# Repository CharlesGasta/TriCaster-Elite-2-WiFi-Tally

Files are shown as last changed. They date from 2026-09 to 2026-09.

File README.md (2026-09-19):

# TriCaster Elite 2 WiFi Tally

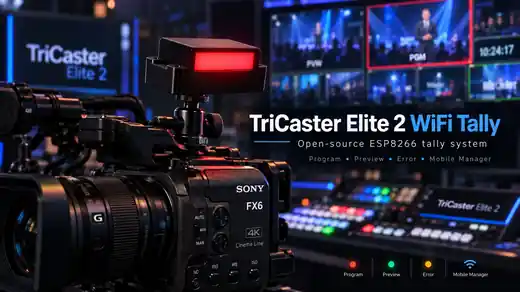
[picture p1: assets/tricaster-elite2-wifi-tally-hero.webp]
TriCaster Elite 2 WiFi Tally


Open-source Wi-Fi tally system for the **NewTek / Vizrt TriCaster Elite 2**, based on inexpensive **ESP8266 NodeMCU** modules.

Each tally unit communicates **directly with the TriCaster Elite 2 over the local network**.  
The optional web Manager is used only for configuration and supervision, so the tally lights continue to work even if the Manager is closed.

---

# Français

## Présentation

Ce projet permet de créer des boîtiers tally Wi-Fi pour **TriCaster Elite 2** à l'aide d'un ESP8266.

Chaque boîtier affiche l'état de la caméra assignée :

- 🔴 **PROGRAM**
- 🟢 **PREVIEW**
- ⚫ **OFF** — ni Program ni Preview
- 🟡 **ERROR** — perte de communication avec le TriCaster
- 🔵 indication réseau / démarrage

Le firmware interroge directement :

```text
http://IP_DU_TRICASTER/v1/dictionary?key=tally
```

Exemple de réponse du TriCaster :

```xml
<column name="input2" index="1" on_pgm="true" on_prev="false" ndi_id="1"/>
```

Le firmware recherche précisément la balise correspondant à `inputX` :

- `on_pgm="true"` → PROGRAM
- `on_prev="true"` → PREVIEW
- les deux à `false` → OFF
- aucune réponse valide pendant environ 2 secondes → ERROR

Le Manager n'est pas indispensable au fonctionnement du tally : les ESP communiquent directement avec le TriCaster Elite 2.

## Matériel nécessaire

Pour chaque tally :

- 1 × **ESP8266 NodeMCU avec USB-C** — modèle utilisé : https://fr.aliexpress.com/item/1005006889833004.html
- 1 × ruban **RGB à anode commune** — modèle utilisé : https://fr.aliexpress.com/item/1005004188897288.html
- **2 LED RGB seulement** sont utilisées dans le boîtier fourni
- 1 × câble **USB-C vers USB-C** pour l'alimentation depuis le port USB-C d'une Sony FX6, ou une alimentation USB-C 5 V classique
- fils, soudure et connecteurs
- 1 × boîtier imprimé en **PLA** à partir du fichier 3D fourni
- 1 × **insert fileté 1/4"** pour fixation sur accessoires caméra — exemple : https://fr.aliexpress.com/item/1005006071559268.html
- accès au même réseau local que le TriCaster Elite 2

Pour l'installation complète :

- 1 × **TriCaster Elite 2**
- 1 × réseau LAN avec Wi-Fi 2,4 GHz
- facultatif : un PC Windows ou le TriCaster lui-même pour exécuter le Manager

> Pour un ruban plus long ou une puissance plus élevée, utilisez des MOSFET/transistors ou un driver LED adapté. Ne faites pas passer une charge importante directement par les sorties de l'ESP8266.

## Réseau Wi-Fi, roaming et installations multi-points d'accès

Le firmware prend en charge **un nombre quelconque de points d'accès Wi-Fi** diffusant le même réseau. Il n'est pas limité à 2 AP : une installation avec **3, 4, 5, 6 AP ou davantage** fonctionne avec la même logique.

### Architecture recommandée

```text
                         ┌── AP 1 ))))
TriCaster ── Switch/LAN ─┼── AP 2 ))))
                         ├── AP 3 ))))
                         ├── AP 4 ))))
                         └── AP N ))))
```

Tous les points d'accès doivent appartenir au **même LAN / même sous-réseau IP** que le TriCaster et les tally.

Pour chaque AP :

- mode **Access Point / Bridge**
- liaison montante **Ethernet filaire** recommandée
- **même SSID**
- **même mot de passe**
- **même mode de sécurité** ; WPA2-PSK est recommandé pour la compatibilité ESP8266
- pas de NAT sur les AP secondaires
- pas de serveur DHCP supplémentaire ; un seul équipement du réseau doit assurer le DHCP
- **Client Isolation / AP Isolation désactivé**
- pas de réseau Guest isolé : les ESP doivent pouvoir joindre le TriCaster et le Manager
- ne pas bloquer l'UDP broadcast local ; le Manager découvre les tally via UDP `4210`
- éviter les fonctions agressives de broadcast/multicast suppression sur le VLAN tally
- les AP peuvent être de marques différentes si ces règles sont respectées
- le 802.11r/k/v n'est pas nécessaire : le firmware ESP8266 gère lui-même la sélection du meilleur BSSID

Évitez le mode répéteur Wi-Fi ou un backhaul radio lorsque vous pouvez tirer un câble Ethernet. Pour une production critique, le **backhaul filaire** est nettement préférable.

### Plan de canaux 2,4 GHz

Utilisez une largeur de canal de **20 MHz** et privilégiez les canaux non chevauchants **1, 6 et 11**.

Exemple pour six AP :

| AP | Canal |
|---|---:|
| AP 1 | 1 |
| AP 2 | 6 |
| AP 3 | 11 |
| AP 4 | 1 |
| AP 5 | 6 |
| AP 6 | 11 |

À partir du 4e AP, réutilisez les canaux en espaçant physiquement autant que possible deux AP utilisant le même canal. Le but est d'éviter que deux cellules voisines émettent sur la même fréquence.

Dans un lieu très grand, une puissance maximale sur tous les AP n'est pas toujours idéale. Commencez avec une puissance adaptée à la zone à couvrir ; si les cellules se chevauchent fortement, réduisez la puissance afin de garder des zones radio distinctes.

Pour une production critique, alimentez idéalement **routeur + switch PoE + AP principaux sur onduleur (UPS)**. Une panne du cœur réseau ferait sinon tomber tous les tally simultanément.

### Roaming automatique des tally

Chaque point d'accès possède un **BSSID** différent, même lorsqu'ils diffusent tous le même SSID. L'ESP8266 garde son IP et choisit automatiquement le BSSID le plus approprié.

Paramètres par défaut :

```cpp
const int ROAM_RSSI_TRIGGER = -70;       // recherche seulement si l'AP courant devient faible
const int ROAM_MIN_GAIN = 8;             // nouvel AP au moins 8 dB meilleur
const unsigned long ROAM_COOLDOWN = 15000;
```

Ainsi, un tally ne change pas d'AP simplement parce qu'un autre est 1 ou 2 dB meilleur. Il reste sur son AP tant que la liaison est correcte, ce qui évite l'effet « yoyo » dans les zones de recouvrement.

Exemple :

```text
AP actuel : -73 dBm
AP voisin : -61 dBm
→ bascule automatique

AP actuel : -71 dBm
AP voisin : -67 dBm
→ aucune bascule
```

Pendant un roaming volontaire, le changement d'AP est **invisible pour le cadreur** : l'ESP conserve le dernier état PROGRAM / PREVIEW / OFF jusqu'à la reprise des données TriCaster.

### Signification des indications réseau

- 🔵 **bleu fixe** : réseau Wi-Fi recherché / hors couverture
- 🔵 **bleu clignotant** : réseau trouvé, association Wi-Fi en cours
- 🟡 **jaune** : Wi-Fi connecté mais communication avec le TriCaster perdue
- lors d'un roaming volontaire vers un meilleur AP : **aucune indication de panne**, le dernier tally reste affiché

Le statut HTTP/heartbeat expose également :

```text
rssi
bssid
channel
wifi_state
```

Ces informations permettent au Manager d'indiquer le point d'accès utilisé par chaque tally et de contrôler la couverture d'une installation multi-AP.

## Boîtier 3D et fixation caméra

Le modèle 3D du boîtier et les informations d'impression sont disponibles sur Thingiverse :

**[Télécharger le modèle 3D sur Thingiverse](https://www.thingiverse.com/thing:7408102)**

Le boîtier est conçu pour être imprimé en **PLA**.

Il prévoit un logement pour un **insert fileté 1/4"**, permettant de fixer directement le tally sur les accessoires de rig caméra courants :

- bras articulé / magic arm
- mini rotule
- adaptateur ou support de griffe flash / cold shoe
- autres accessoires de bijout caméra utilisant une fixation 1/4"

Exemple d'insert utilisé :

https://fr.aliexpress.com/item/1005006071559268.html

Le boîtier a été conçu autour de **2 LED RGB** seulement.

### Alimentation sur caméra

Sur une **Sony FX6**, le tally peut être alimenté directement depuis le port USB-C de la caméra avec un câble **USB-C vers USB-C**.

Si aucun port USB-C caméra n'est disponible, une simple alimentation **5 V USB-C** suffit.

## Câblage

Configuration testée avec ruban RGB **anode commune** :

| ESP8266 | RGB |
|---|---|
| `3V3` | `+` commun |
| `D1` | Vert |
| `D2` | Rouge |
| `D3` | Bleu |

La logique PWM est inversée car il s'agit d'une anode commune.

> Sur beaucoup de cartes NodeMCU, `D3` correspond à GPIO0, qui intervient aussi au démarrage. Si l'ESP refuse de booter avec le ruban connecté, débranchez temporairement cette ligne pendant le flash ou changez le brochage dans le firmware.

## Animation au démarrage

```text
Noir → Rouge → Jaune → Vert → Cyan → Bleu → Magenta → Rouge → Noir
```

puis trois flashs blancs rapides.

## Installation du firmware

1. Installer **Arduino IDE**.
2. Installer **esp8266 by ESP8266 Community**.
3. Sélectionner :
   ```text
   NodeMCU 1.0 (ESP-12E Module)
   ```
4. Ouvrir :
   ```text
   TriCaster_Elite2_Tally_ESP8266.ino
   ```
5. Choisir uniquement le numéro du boîtier avant le premier flash :

```cpp
#define DEFAULT_TALLY_NUMBER 1
```

> **Important :** `DEFAULT_TALLY_NUMBER` sert uniquement lorsqu'aucune configuration valide n'est encore enregistrée dans l'EEPROM. Si un ESP a déjà été configuré comme `TALLY-06 / CAM 6`, le reflasher avec `DEFAULT_TALLY_NUMBER 5` **ne le renomme pas automatiquement** : la configuration EEPROM est volontairement conservée. Le nom et la caméra peuvent être changés depuis le Manager, ou l'EEPROM peut être effacée pour repartir comme un boîtier neuf.

6. Compiler puis téléverser.

Le firmware V4 conserve toujours des valeurs par défaut compilables :

```cpp
const char* DEFAULT_WIFI_SSID = "YOUR_WIFI_SSID";
const char* DEFAULT_WIFI_PASSWORD = "YOUR_WIFI_PASSWORD";
const char* DEFAULT_ADMIN_TOKEN = "CHANGE_ME";
```

Mais **il n'est plus nécessaire de reflasher le tally pour changer le réseau**.

Moniteur série :

```text
115200 baud
```

---

## Configuration réseau sans reflasher

### Premier démarrage / réseau introuvable

Au démarrage, le tally cherche le réseau enregistré. S'il ne le trouve pas pendant environ **30 secondes**, il crée automatiquement son propre point d'accès :

```text
TALLY-01-SETUP
TALLY-02-SETUP
...
```

Le mot de passe de ce Wi-Fi SETUP est le **token administrateur**. Sur un firmware neuf, la valeur initiale est :

```text
CHANGE_ME
```

Connectez un téléphone ou un ordinateur au réseau `TALLY-XX-SETUP`, puis ouvrez :

```text
http://192.168.4.1/
```

Le portail permet de régler :

- nom du tally
- SSID Wi-Fi 2,4 GHz
- mot de passe Wi-Fi
- mode **DHCP** ou **IP statique**
- IP, gateway, subnet et DNS en mode statique
- IP du TriCaster
- token administrateur

Après validation, l'ESP enregistre la configuration en EEPROM puis redémarre.

> Pour la sécurité, remplacez immédiatement `CHANGE_ME` par un token personnel de **8 à 32 caractères**. Ce token protège l'API d'administration, la mise à jour OTA et le réseau de secours `TALLY-XX-SETUP`.

### DHCP ou IP statique

Les deux modes sont supportés.

**IP statique** est pratique pour un parc broadcast fixe :

```text
TALLY-01 : 192.168.1.81
TALLY-02 : 192.168.1.82
...
```

Gardez ces adresses **hors de la plage DHCP** du routeur.

**DHCP** est pratique lorsque le système est déplacé sur des réseaux différents. Pour conserver des adresses prévisibles, utilisez de préférence des **réservations DHCP** sur le routeur.

Le Manager V4 permet ensuite de modifier ces paramètres à distance sans reflasher l'ESP.

### Migration depuis l'ancien firmware

Le firmware V4 reconnaît automatiquement la configuration EEPROM de la version précédente et conserve notamment :

- nom du tally
- IP statique
- IP TriCaster
- caméra assignée
- couleurs PROGRAM / PREVIEW
- luminosité

Les nouveaux paramètres réseau sont ajoutés avec leurs valeurs par défaut.

---

## Affectation caméra / entrée

Par défaut :

```cpp
config.camera = constrain(DEFAULT_TALLY_NUMBER, 1, 8);
```

Donc :

```text
TALLY-01 → input1
TALLY-02 → input2
TALLY-03 → input3
...
```

L'affectation peut ensuite être modifiée depuis le Manager sans reflasher l'ESP.

---

## Tally Manager V4.1

### Téléchargement Windows prêt à l'emploi

La dernière version compilée est publiée dans **GitHub Releases** :

https://github.com/CharlesGasta/TriCaster-Elite-2-WiFi-Tally/releases/latest

Téléchargez `TriCaster_Elite2_Tally_Manager.exe`. Si une tâche planifiée Windows lance déjà une ancienne version par un nom de fichier précis, remplacez simplement l'ancien EXE au même emplacement **en conservant exactement le nom attendu par la tâche**.

Fichier source :

```text
TriCaster_Elite2_Tally_Manager.py
```

Le Manager n'est toujours **pas dans le chemin critique du tally** : si le Manager est fermé, chaque ESP continue à lire directement le TriCaster.

Le Manager V4.1 fournit :

- détection automatique des tally
- état connecté / hors ligne
- RSSI avec indication visuelle de qualité
- **BSSID / point d'accès utilisé**
- nom convivial des AP, par exemple `AP TERRAIN`, `AP TRIBUNE`
- canal Wi-Fi
- état Wi-Fi : `connected`, `roaming`, `searching`, `connecting`
- version firmware
- uptime ESP
- latence de réponse TriCaster
- compteur de roamings
- compteur de pertes Wi-Fi
- compteur de pertes TriCaster
- affectation caméra 1 à 32
- couleurs PROGRAM / PREVIEW
- luminosité
- Identify
- reboot distant
- configuration complète du réseau ESP
- DHCP / IP statique
- modification de l'IP TriCaster
- **PRE-FLIGHT / GO-NO-GO** avant production : tally attendus, online/offline, RSSI, latence TriCaster, doublons IP/caméra, versions firmware et cohérence de l'IP TriCaster
- **MODE PRODUCTION** persistant : verrouille OTA, reboot, Identify, affectations, couleurs, luminosité et configuration réseau
- **OTA sécurisée** par tally, sélection ou parc complet : redémarrage et retour sain vérifiés avant de passer au boîtier suivant, avec arrêt au premier échec
- **journal persistant des incidents et actions** avec export CSV : pertes Wi-Fi/TriCaster, roaming, offline/recovery, reboot, OTA et changements de configuration
- **mise à jour OTA de tous les tally connectés**
- interface desktop et mobile

Ports utilisés :

| Fonction | Port |
|---|---|
| Interface web Manager | TCP `8099` |
| Discovery / heartbeat | UDP `4210` |
| API / OTA ESP8266 | TCP `80` |

Interface locale :

```text
http://127.0.0.1:8099
```

Depuis un téléphone sur le même réseau :

```text
http://IP_DU_PC_MANAGER:8099/mobile
```

### Authentification

Le Manager et les opérations d'administration des ESP utilisent une authentification HTTP Basic :

```text
Utilisateur : admin
Mot de passe : token administrateur
```

La configuration persistante du Manager est enregistrée à côté du script / EXE dans :

```text
tally_manager_config.json
```

Valeur initiale publique :

```json
{
  "api_token": "CHANGE_ME",
  "ap_aliases": {},
  "production_mode": false,
  "expected_tally_count": 0
}
```

Remplacez `CHANGE_ME` par le **même token que celui configuré dans les ESP** avant une utilisation sur un réseau partagé.

> Le protocole d'administration reste HTTP sur le LAN. Le réseau tally doit donc rester privé / isolé et ne doit pas être exposé directement à Internet.

### Mise à jour OTA

1. Dans Arduino IDE, compilez le firmware et exportez le binaire `.bin`.
2. Ouvrez le Manager V4.
3. Sélectionnez le fichier `.bin` dans **Firmware OTA**.
4. Cliquez **METTRE À JOUR TOUS LES TALLY**.

Le Manager envoie le firmware séquentiellement à tous les tally actuellement en ligne. Chaque ESP redémarre automatiquement après une mise à jour réussie.

Conservez toujours un premier boîtier de test avant de lancer une mise à jour de parc pendant une période de production.

### PRE-FLIGHT et mode production

Avant un direct, renseignez le nombre de tally attendus puis cliquez **CHECK PRODUCTION**.

Le Manager retourne :

```text
GO         aucun problème détecté
ATTENTION  avertissement non bloquant
NO-GO      au moins une erreur critique
```

Le contrôle vérifie notamment les boîtiers en ligne, le RSSI, la latence et la fraîcheur des données TriCaster, les doublons IP/caméra, les versions firmware et la cohérence de l'adresse TriCaster.

Après validation, activez **MODE PRODUCTION**. Le verrou est persistant et reste actif après un redémarrage du Manager. Il bloque côté serveur les commandes susceptibles de perturber un direct : OTA, reboot, Identify, affectations, couleurs, luminosité et configuration réseau.

### OTA sécurisée V4.1

L'OTA peut cibler :

- un seul tally
- une sélection de tally
- tous les tally en ligne

Les boîtiers sont traités **séquentiellement**. Après chaque envoi, le Manager attend un vrai redémarrage puis vérifie que le boîtier est revenu avec Wi-Fi connecté et données TriCaster fraîches. Par défaut, le déploiement s'arrête au premier échec.

### Journal persistant

Le Manager crée à côté de l'EXE / du script :

```text
tally_manager_events.csv
```

Le journal conserve les événements importants avec date et heure : offline/recovery, pertes Wi-Fi, pertes TriCaster, roaming, erreurs tally, reboot, changements de configuration et OTA. Il est consultable dans l'interface et exportable en CSV. Une rotation automatique conserve le journal précédent lorsque le fichier courant dépasse environ 5 Mo.

### Diagnostic de couverture

Chaque heartbeat expose notamment :

```text
firmware
rssi
bssid
channel
wifi_state
uptime_ms
tricaster_latency_ms
last_tally_age_ms
roam_count
wifi_loss_count
tricaster_loss_count
last_roam_age_ms
```

Repères pratiques pour le RSSI :

```text
>= -65 dBm     très bon
-66 à -72 dBm  acceptable / à surveiller
< -72 dBm      zone à améliorer
```

---

## Compiler le Manager en EXE

Installer PyInstaller :

```powershell
py -m pip install pyinstaller
```

Version avec console :

```powershell
py -m PyInstaller --noconfirm --clean --onefile --console --name TriCaster_Elite2_Tally_Manager TriCaster_Elite2_Tally_Manager.py
```

Version silencieuse pour fonctionnement en arrière-plan :

```powershell
py -m PyInstaller --noconfirm --clean --onefile --windowed --name TriCaster_Elite2_Tally_Manager TriCaster_Elite2_Tally_Manager.py
```

L'exécutable sera dans :

```text
dist\TriCaster_Elite2_Tally_Manager.exe
```

---

## Démarrage automatique sur le TriCaster

Avec le **Task Scheduler** Windows :

```text
Trigger                 : At log on
Run only when logged on : Yes
Run with highest privileges
Action                  : TriCaster_Elite2_Tally_Manager.exe
If already running      : Do not start a new instance
```

Cela fonctionne particulièrement bien sur un TriCaster configuré avec ouverture automatique de session Windows.

---

# English

## Overview

This project provides low-cost Wi-Fi tally units for the **NewTek / Vizrt TriCaster Elite 2** using ESP8266 NodeMCU boards.

Each tally reads the TriCaster tally state directly over the local network and displays:

- 🔴 **PROGRAM**
- 🟢 **PREVIEW**
- ⚫ **OFF**
- 🟡 **ERROR / TriCaster connection lost**
- 🔵 network/startup indication

The ESP8266 queries:

```text
http://TRICASTER_IP/v1/dictionary?key=tally
```

A typical response contains:

```xml
<column name="input2" index="1" on_pgm="true" on_prev="false" ndi_id="1"/>
```

The firmware isolates the exact `inputX` XML element:

- `on_pgm="true"` → PROGRAM
- `on_prev="true"` → PREVIEW
- both `false` → OFF
- no valid response for roughly 2 seconds → ERROR

The optional Manager is not part of the critical tally path. Each ESP communicates directly with the TriCaster Elite 2.

## Required hardware

For each tally:

- 1 × **ESP8266 NodeMCU with USB-C** — board used: https://fr.aliexpress.com/item/1005006889833004.html
- 1 × **common-anode RGB LED strip** — strip used: https://fr.aliexpress.com/item/1005004188897288.html
- the supplied enclosure uses **2 RGB LEDs only**
- 1 × **USB-C to USB-C cable** for power from a Sony FX6 USB-C port, or a standard 5 V USB-C power supply
- wiring / solder / connectors
- 1 × **PLA** 3D-printed enclosure using the supplied model
- 1 × **1/4-inch threaded insert** for camera-rig mounting — example: https://fr.aliexpress.com/item/1005006071559268.html
- access to the same network as the TriCaster Elite 2

Overall system:

- 1 × **TriCaster Elite 2**
- LAN with 2.4 GHz Wi-Fi
- optional Windows computer, or the TriCaster itself, for the Manager

## Wi-Fi network, roaming and multi-AP deployments

The firmware supports **any number of Wi-Fi access points** broadcasting the same network. It is not limited to two APs: deployments with **3, 4, 5, 6 or more APs** use the same roaming logic.

Recommended topology:

```text
                         ┌── AP 1 ))))
TriCaster ── Switch/LAN ─┼── AP 2 ))))
                         ├── AP 3 ))))
                         ├── AP 4 ))))
                         └── AP N ))))
```

All APs must be on the **same Layer-2 LAN / IP subnet** as the TriCaster and tally units.

Configure every AP with:

- **Access Point / Bridge** mode
- preferably a **wired Ethernet backhaul**
- the **same SSID**
- the **same password**
- the **same security mode**; WPA2-PSK is recommended for ESP8266 compatibility
- no NAT on secondary APs
- no additional DHCP server; use one DHCP server for the LAN
- **Client Isolation / AP Isolation disabled**
- do not use an isolated guest network; ESP units must reach the TriCaster and Manager
- allow local UDP broadcast; the Manager discovers tally units on UDP `4210`
- avoid aggressive broadcast/multicast suppression on the tally VLAN
- different AP brands are acceptable when these requirements are met
- 802.11r/k/v is not required; the ESP8266 firmware performs its own BSSID selection

For production use, wired backhaul is strongly preferred over wireless repeater/mesh backhaul.

### 2.4 GHz channel plan

Use **20 MHz** channel width and the non-overlapping channels **1, 6 and 11**.

For six APs, a typical plan is:

| AP | Channel |
|---|---:|
| AP 1 | 1 |
| AP 2 | 6 |
| AP 3 | 11 |
| AP 4 | 1 |
| AP 5 | 6 |
| AP 6 | 11 |

From the fourth AP onward, reuse channels only with as much physical separation as practical between APs sharing the same channel.

For critical productions, power the **router + PoE switch + main APs from a UPS** whenever practical. A failure of the network core would otherwise affect every tally at once.

### Automatic roaming

Every AP has a different **BSSID**, even when all APs use the same SSID. The tally keeps its IP address and automatically selects a better BSSID when necessary.

Default V4.2 roaming parameters:

```cpp
const int ROAM_RSSI_TRIGGER = -72;
const int ROAM_MIN_GAIN = 10;
const unsigned long ROAM_SCAN_INTERVAL = 30000;
const unsigned long ROAM_COOLDOWN = 30000;
const unsigned long ROAM_STARTUP_GRACE = 30000;
```

Initial connection and recovery use standard **SSID + password** association. A specific BSSID is forced only during an intentional roaming handoff to a clearly stronger AP. No proactive roaming scan is allowed during the first 30 seconds after a Wi-Fi connection.

The tally therefore stays on its current AP while the link remains usable and only moves when another AP is clearly better, preventing ping-pong roaming in overlap areas.

During intentional roaming, the switch is **invisible to the camera operator**: the last PROGRAM / PREVIEW / OFF state remains displayed until TriCaster polling resumes.

Network indications:

- 🔵 **solid blue**: searching for the Wi-Fi network / out of coverage
- 🔵 **blinking blue**: network found, Wi-Fi association in progress
- 🟡 **yellow**: Wi-Fi is connected but TriCaster communication is lost
- intentional roaming: no fault indication; the previous tally state is held

The status/heartbeat payload also includes `rssi`, `bssid`, `channel` and `wifi_state` for multi-AP diagnostics.

## 3D-printed enclosure and camera mounting

The enclosure 3D model and print information are available on Thingiverse:

**[Download the 3D model on Thingiverse](https://www.thingiverse.com/thing:7408102)**

The enclosure is designed to be printed in **PLA**.

It includes a seat for a **1/4-inch threaded insert**, allowing the tally to be mounted to common camera-rig accessories such as:

- magic arms / articulated arms
- mini ball heads
- cold-shoe / flash-shoe adapters
- other camera accessories using a 1/4-inch mounting thread

Example threaded insert:

https://fr.aliexpress.com/item/1005006071559268.html

The enclosure is designed around **2 RGB LEDs only**.

### Camera power

On a **Sony FX6**, the tally can be powered directly from the camera's USB-C port using a **USB-C to USB-C cable**.

If camera USB-C power is not available, any standard **5 V USB-C power supply** is sufficient.

## Wiring

| ESP8266 | RGB |
|---|---|
| `3V3` | Common `+` |
| `D1` | Green |
| `D2` | Red |
| `D3` | Blue |

The firmware uses inverted PWM for a common-anode RGB strip.

## Firmware installation

1. Install Arduino IDE.
2. Install **esp8266 by ESP8266 Community**.
3. Select:
   ```text
   NodeMCU 1.0 (ESP-12E Module)
   ```
4. Open:
   ```text
   TriCaster_Elite2_Tally_ESP8266.ino
   ```
5. Select the tally number before the first flash:

```cpp
#define DEFAULT_TALLY_NUMBER 1
```

> **Important:** `DEFAULT_TALLY_NUMBER` is only used when no valid configuration is already stored in EEPROM. If an ESP is already configured as `TALLY-06 / CAM 6`, reflashing it with `DEFAULT_TALLY_NUMBER 5` **will not rename it automatically**: the saved EEPROM configuration is intentionally preserved. Change the name/camera from the Manager, or erase EEPROM to start as a new unit.

6. Compile and upload.

V4 still contains compile-time fallback defaults:

```cpp
const char* DEFAULT_WIFI_SSID = "YOUR_WIFI_SSID";
const char* DEFAULT_WIFI_PASSWORD = "YOUR_WIFI_PASSWORD";
const char* DEFAULT_ADMIN_TOKEN = "CHANGE_ME";
```

However, **network settings no longer require reflashing the ESP**.

Serial monitor:

```text
115200 baud
```

## Network setup without reflashing

### First boot / configured Wi-Fi unavailable

At startup, the tally searches for the stored Wi-Fi network. If it cannot find it for about **30 seconds**, it automatically creates:

```text
TALLY-01-SETUP
TALLY-02-SETUP
...
```

The SETUP Wi-Fi password is the **administrator token**. On a new public firmware build the initial value is:

```text
CHANGE_ME
```

Connect a phone or computer to `TALLY-XX-SETUP`, then open:

```text
http://192.168.4.1/
```

The setup portal can configure:

- tally name
- 2.4 GHz Wi-Fi SSID
- Wi-Fi password
- **DHCP** or **static IP**
- IP, gateway, subnet and DNS in static mode
- TriCaster IP
- administrator token

The ESP saves the configuration to EEPROM and reboots.

> Replace `CHANGE_ME` immediately with a private **8 to 32 character** token. The token protects the administration API, OTA updates and the fallback `TALLY-XX-SETUP` network.

### DHCP or static IP

Both modes are supported.

Static addresses are convenient for a fixed broadcast system:

```text
TALLY-01 : 192.168.1.81
TALLY-02 : 192.168.1.82
...
```

Keep static tally addresses outside the DHCP pool.

DHCP is convenient for portable deployments. For predictable addresses, use **DHCP reservations** on the router.

The V4.1 Manager can change these settings remotely without reflashing the ESP.

### Migration from previous firmware

V4 automatically recognizes the previous EEPROM layout and preserves the existing tally name, static IP, TriCaster IP, camera assignment, colors and brightness while adding the new V4 network settings.

## Camera/input assignment

By default:

```cpp
config.camera = constrain(DEFAULT_TALLY_NUMBER, 1, 8);
```

Therefore:

```text
TALLY-01 → input1
TALLY-02 → input2
TALLY-03 → input3
...
```

Assignments can later be changed from the Manager without reflashing the tally.

## Manager V4.1

### Ready-to-run Windows download

The latest compiled release is available from:

https://github.com/CharlesGasta/TriCaster-Elite-2-WiFi-Tally/releases/latest

Download `TriCaster_Elite2_Tally_Manager.exe`. Existing Windows startup tasks can keep working by replacing the previous executable at the same path while preserving the filename expected by the scheduled task.

Source file:

```text
TriCaster_Elite2_Tally_Manager.py
```

The Manager is still **not part of the critical tally path**. If the Manager is closed, every ESP continues polling the TriCaster directly.

V4.1 features include:

- automatic tally discovery
- online/offline status
- RSSI with quality indication
- current **AP / BSSID**
- friendly AP names such as `COURT AP` or `STANDS AP`
- Wi-Fi channel
- Wi-Fi state: `connected`, `roaming`, `searching`, `connecting`
- firmware version
- ESP uptime
- TriCaster response latency
- roaming counter
- Wi-Fi loss counter
- TriCaster loss counter
- camera/input assignment from 1 to 32
- PROGRAM / PREVIEW colors
- brightness
- Identify
- remote reboot
- full ESP network configuration
- DHCP / static IP
- TriCaster IP configuration
- **pre-flight GO / ATTENTION / NO-GO checks**
- persistent server-side **Production Mode** lock
- **verified staged OTA** for one tally, a selection or the complete online fleet, stopping on first failure by default
- **persistent event/incident logging** with CSV export
- **fleet OTA update for all online tally units**
- desktop and mobile UI

Ports:

| Function | Port |
|---|---|
| Manager web UI | TCP `8099` |
| Discovery / heartbeat | UDP `4210` |
| ESP8266 API / OTA | TCP `80` |

Local UI:

```text
http://127.0.0.1:8099
```

Mobile/LAN UI:

```text
http://MANAGER_PC_IP:8099/mobile
```

### Authentication

The Manager and ESP administration endpoints use HTTP Basic authentication:

```text
Username : admin
Password : administrator token
```

Persistent Manager settings are stored next to the script / EXE:

```text
tally_manager_config.json
```

Default public configuration:

```json
{
  "api_token": "CHANGE_ME",
  "ap_aliases": {}
}
```

Replace `CHANGE_ME` with the **same token configured on the ESP units** before using the system on a shared network.

> Administration uses HTTP on the local LAN. Keep the tally network private / isolated and do not expose these endpoints directly to the Internet.

### V4.2 validation status

V4.2 is the current clean firmware baseline. Before promoting it as the final production release, validate the complete six-unit fleet using [TEST_PLAN_V4_2.md](TEST_PLAN_V4_2.md).

### Firmware V4.2 clean baseline

V4.2 is the cleaned production baseline after hardware testing isolated a defective ESP8266 module. The temporary test-specific TALLY-04 source has been removed from the repository.

Kept in V4.2 because they are useful independently of that hardware fault:

- standard SSID/password association for initial Wi-Fi connection and recovery
- DHCP or static IP
- setup portal after failed startup connection
- explicit current DHCP IP in status data
- Wi-Fi disconnect reason logging and ESP station MAC in Serial Monitor
- direct TriCaster polling at 250 ms
- PROGRAM / PREVIEW / ERROR LED states
- Manager heartbeat and diagnostics
- authenticated OTA
- conservative multi-AP roaming with a 30 s grace period, -72 dBm trigger and 10 dB minimum gain

### Firmware files: `.ino` and `.bin`

Every firmware build publishes **both files together** in the GitHub Actions artifact:

```text
TriCaster_Elite2_Tally_ESP8266.ino
TriCaster_Elite2_Tally_ESP8266.bin
```

Why both are provided:

- `.ino` = Arduino source code. Use this when an ESP cannot reach the Manager, after a full flash erase, or when flashing directly over USB from Arduino IDE.
- `.bin` = already-compiled firmware. Use this for OTA updates from the Tally Manager; Arduino IDE does not open it as a sketch.

### OTA firmware update

1. Use the compiled `.bin` from the matching GitHub firmware artifact.
2. Open Manager V4.1.
3. Select the `.bin` file under **Firmware OTA**.
4. Click **UPDATE ALL TALLY UNITS** / the corresponding V4.1 update button.

The Manager sends the firmware sequentially to every currently online tally. Each ESP reboots automatically after a successful update.

Always validate a new firmware on one test tally before deploying it to a live production fleet.

### Pre-flight and Production Mode

Set the expected tally count, then run **CHECK PRODUCTION** before going live. The Manager checks online/offline units, RSSI, TriCaster latency and data age, duplicate IP/camera assignments, firmware consistency and TriCaster IP consistency.

After validation, enable **Production Mode**. The lock persists across Manager restarts and is enforced server-side, blocking OTA, reboot, Identify and configuration changes while live.

### Verified staged OTA

V4.1 can update one tally, a selected group or all online devices. Devices are processed sequentially. After each upload the Manager waits for an actual reboot and verifies that Wi-Fi and TriCaster tally data have recovered before continuing. Deployment stops on the first failed verification by default.

### Persistent event log

The Manager writes `tally_manager_events.csv` beside the executable/script. It records important Wi-Fi, TriCaster, roaming, offline/recovery, reboot, configuration and OTA events and can be exported from the UI. The active log automatically rotates at roughly 5 MB.

### Coverage diagnostics

Heartbeat/status data includes:

```text
firmware
rssi
bssid
channel
wifi_state
uptime_ms
tricaster_latency_ms
last_tally_age_ms
roam_count
wifi_loss_count
tricaster_loss_count
last_roam_age_ms
```

Useful RSSI reference:

```text
>= -65 dBm     very good
-66 to -72     usable / monitor
< -72 dBm      improve coverage
```

## Building the Windows Manager

```powershell
py -m pip install pyinstaller
```

Console build:

```powershell
py -m PyInstaller --noconfirm --clean --onefile --console --name TriCaster_Elite2_Tally_Manager TriCaster_Elite2_Tally_Manager.py
```

Background build:

```powershell
py -m PyInstaller --noconfirm --clean --onefile --windowed --name TriCaster_Elite2_Tally_Manager TriCaster_Elite2_Tally_Manager.py
```

## Automatic startup

Recommended Windows Task Scheduler configuration:

```text
Trigger                 : At log on
Run only when logged on : Yes
Run with highest privileges
Action                  : TriCaster_Elite2_Tally_Manager.exe
If already running      : Do not start a new instance
```

## License

MIT License.

## Disclaimer

This is an independent open-source project for use with TriCaster Elite 2 systems.  
NewTek, Vizrt and TriCaster are trademarks of their respective owners. This project is not affiliated with or endorsed by Vizrt or NewTek.

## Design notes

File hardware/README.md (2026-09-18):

# 3D enclosure

The enclosure is designed for the TriCaster Elite 2 WiFi Tally and should be printed in **PLA**.

The 3D model and print information are available here:

https://www.thingiverse.com/thing:7408102

The enclosure is designed around **2 RGB LEDs** and includes a seat for a **1/4-inch threaded insert** so it can be mounted to common camera-rig accessories such as magic arms, mini ball heads and cold-shoe / flash-shoe adapters.

Example threaded insert:
https://fr.aliexpress.com/item/1005006071559268.html

The ESP8266 used in the build is a USB-C model:
https://fr.aliexpress.com/item/1005006889833004.html

RGB strip used:
https://fr.aliexpress.com/item/1005004188897288.html

On a Sony FX6, the tally can be powered directly from the camera USB-C port using a USB-C to USB-C cable. A standard 5 V USB-C power supply can also be used.

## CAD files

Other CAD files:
hardware/TALLY_TRICASTER_v6.3mf

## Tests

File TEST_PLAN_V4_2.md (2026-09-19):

# V4.2 field validation plan

Use this checklist before publishing V4.2 as the production baseline.

## Fleet

Validate all 6 tally units together on the same production LAN.

## 1. Startup

For every tally:

- boots normally
- joins the configured 2.4 GHz Wi-Fi
- receives the expected DHCP/static address
- appears in the Manager
- correct tally name and camera assignment
- firmware reports V4.2.0
- RSSI, BSSID, channel and DHCP IP are visible
- no repeated Wi-Fi disconnect reason in Serial Monitor

## 2. TriCaster tally states

For every assigned input:

- PROGRAM -> red
- PREVIEW -> green
- neither -> LEDs off
- TriCaster unavailable -> yellow/error
- recovery restores the correct tally state without reboot

## 3. Stability soak

Run all 6 tally units continuously for at least 60 minutes.

Pass criteria:

- no unexplained Manager offline event
- no ESP reboot
- no progressive latency increase
- heartbeat remains regular
- Wi-Fi loss counters stay stable in fixed coverage

## 4. Multi-AP roaming

Test only where multiple APs use the same SSID/security and the same Layer-2 LAN.

- move a tally from good coverage on AP A toward AP B
- roaming should only start below about -72 dBm
- target AP should be at least 10 dB better
- PROGRAM/PREVIEW display should remain visually stable during the handoff
- Manager should show the new BSSID/channel afterward
- no repeated ping-pong between APs

## 5. Manager controls

Check:

- camera assignment
- brightness
- PROGRAM/PREVIEW colors
- Identify
- reboot
- DHCP/static configuration
- displayed current DHCP IP
- Production Mode lock
- pre-flight report

## 6. OTA

Test on one tally first:

1. select one tally
2. upload the matching V4.2 .bin
3. verify reboot and return to Manager
4. verify firmware version, Wi-Fi and tally data
5. only then test a selected group
6. deploy to the remaining units only after successful validation

## Acceptance

V4.2 can be treated as production-ready after all 6 units complete the soak, roaming and OTA tests without unexplained disconnects or reboots.

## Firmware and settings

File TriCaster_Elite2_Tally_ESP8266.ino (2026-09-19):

#include <ESP8266WiFi.h>
#include <ESP8266WebServer.h>
#include <ESP8266HTTPClient.h>
#include <ESP8266HTTPUpdateServer.h>
#include <DNSServer.h>
#include <WiFiUdp.h>
#include <EEPROM.h>

// =====================================================
// TRICASTER ELITE 2 WIFI TALLY - ESP8266
// Modifier uniquement ce numéro avant le premier flash.
// Exemple public : 1 = 192.168.1.81, 2 = .82, ... 8 = .88
// =====================================================
#define DEFAULT_TALLY_NUMBER 1
#define FIRMWARE_VERSION "4.2.0"

// Valeurs utilisees au premier flash / apres reset usine.
// Elles peuvent ensuite etre modifiees sans reflasher via le portail SETUP
// ou depuis le Tally Manager.
const char* DEFAULT_WIFI_SSID = "YOUR_WIFI_SSID";
const char* DEFAULT_WIFI_PASSWORD = "YOUR_WIFI_PASSWORD";
const char* DEFAULT_ADMIN_TOKEN = "CHANGE_ME";

#define PIN_GREEN D1
#define PIN_RED   D2
#define PIN_BLUE  D3
#define LED_ON LOW
#define LED_OFF HIGH

const uint32_t LEGACY_CONFIG_MAGIC = 0xCA12AC06;
const uint32_t CONFIG_MAGIC = 0xCA12AC08;
const unsigned long POLL_INTERVAL = 250;
const unsigned long TALLY_TIMEOUT = 2000;
const unsigned long HEARTBEAT_INTERVAL = 1000;
const unsigned long IDENTIFY_DURATION = 5000;

// Roaming Wi-Fi entre plusieurs points d'acces utilisant le meme SSID.
// Le scan ne se lance que si le signal devient faible afin de ne pas
// perturber inutilement le polling tally.
const int ROAM_RSSI_TRIGGER = -72;                // dBm : chercher un meilleur AP seulement si necessaire
const int ROAM_MIN_GAIN = 10;                    // dB  : evite les bascules pour un faible gain
const unsigned long ROAM_SCAN_INTERVAL = 30000;  // ms  : limite les scans radio
const unsigned long ROAM_COOLDOWN = 30000;       // ms  : evite le ping-pong entre AP
const unsigned long ROAM_CONNECT_TIMEOUT = 8000; // ms  : abandon d'une tentative de roaming
const unsigned long ROAM_STARTUP_GRACE = 30000;  // ms  : aucun roaming juste apres une connexion

// Roaming proactif active pour les installations multi-AP.
// La connexion initiale et la reconnexion apres perte restent des connexions
// standard SSID + mot de passe. Le BSSID n'est force que lors d'un roaming
// volontaire vers un AP clairement meilleur.
const bool PROACTIVE_ROAMING_ENABLED = true;

// Reconnexion apres une vraie perte Wi-Fi.
// Bleu fixe = recherche du SSID.
// Bleu clignotant = SSID trouve, association Wi-Fi en cours.
const unsigned long WIFI_CONNECT_TIMEOUT = 8000;
const unsigned long WIFI_SCAN_RETRY = 1000;
const unsigned long BLUE_BLINK_INTERVAL = 250;

// Si aucun Wi-Fi configure n'est joignable au demarrage, le portail
// TALLY-XX-SETUP est active automatiquement apres ce delai.
const unsigned long STARTUP_SETUP_TIMEOUT = 30000;
const byte DNS_PORT = 53;

struct LegacyConfigV3 {
  uint32_t magic;
  char name[32];
  uint8_t ip[4];
  uint8_t tricaster[4];
  uint8_t camera;
  uint8_t pgmR, pgmG, pgmB;
  uint8_t prevR, prevG, prevB;
  uint8_t brightness;
};

struct Config {
  uint32_t magic;

  char name[32];
  char ssid[33];
  char wifiPassword[65];
  char adminToken[33];

  bool dhcp;
  uint8_t ip[4];
  uint8_t gateway[4];
  uint8_t subnet[4];
  uint8_t dns[4];

  uint8_t tricaster[4];
  uint8_t camera;

  uint8_t pgmR, pgmG, pgmB;
  uint8_t prevR, prevG, prevB;
  uint8_t brightness;
};

Config config;
ESP8266WebServer server(80);
ESP8266HTTPUpdateServer httpUpdater;
DNSServer dnsServer;
WiFiUDP udp;
WiFiEventHandler wifiDisconnectedHandler;

bool setupPortalActive = false;

enum TallyState { STATE_OFF, STATE_PREVIEW, STATE_PROGRAM, STATE_ERROR };
enum WiFiRecoveryState { WIFI_NORMAL, WIFI_SEARCHING, WIFI_CONNECTING };

TallyState currentState = STATE_OFF;
WiFiRecoveryState wifiRecoveryState = WIFI_SEARCHING;

bool identifyActive = false;
unsigned long identifyStart = 0;
unsigned long lastPoll = 0;
unsigned long lastGoodTally = 0;
unsigned long lastHeartbeat = 0;

unsigned long lastRoamCheck = 0;
unsigned long lastRoamAt = 0;
unsigned long wifiConnectedAt = 0;
bool roamScanRunning = false;
bool roamInProgress = false;
bool roamTargetValid = false;
uint8_t roamTargetBssid[6] = {0,0,0,0,0,0};

bool recoveryScanRunning = false;
unsigned long recoveryConnectStart = 0;
unsigned long lastRecoveryScanAt = 0;

// Supervision / diagnostic
uint32_t roamCount = 0;
uint32_t wifiLossCount = 0;
uint32_t tricasterLossCount = 0;
unsigned long lastRoamCompletedAt = 0;
unsigned long lastTriCasterLatency = 0;

IPAddress broadcastIP(192, 168, 1, 255);

IPAddress savedIP() {
  return IPAddress(config.ip[0], config.ip[1], config.ip[2], config.ip[3]);
}

IPAddress gatewayIP() {
  return IPAddress(config.gateway[0], config.gateway[1], config.gateway[2], config.gateway[3]);
}

IPAddress subnetIP() {
  return IPAddress(config.subnet[0], config.subnet[1], config.subnet[2], config.subnet[3]);
}

IPAddress dnsIP() {
  return IPAddress(config.dns[0], config.dns[1], config.dns[2], config.dns[3]);
}

IPAddress tricasterIP() {
  return IPAddress(config.tricaster[0], config.tricaster[1], config.tricaster[2], config.tricaster[3]);
}

void copyIP(uint8_t target[4], const IPAddress& source) {
  for (int i = 0; i < 4; i++) target[i] = source[i];
}

void updateBroadcastIP() {
  IPAddress local = WiFi.localIP();
  IPAddress mask = WiFi.subnetMask();

  // En IP statique, certains firmwares renvoient 0.0.0.0 tres tot.
  if (local == IPAddress(0,0,0,0)) local = savedIP();
  if (mask == IPAddress(0,0,0,0)) mask = subnetIP();

  for (int i = 0; i < 4; i++) {
    broadcastIP[i] = local[i] | (uint8_t)(~mask[i]);
  }
}

void applyNetworkConfig() {
  if (config.dhcp) {
    WiFi.config(IPAddress(0,0,0,0), IPAddress(0,0,0,0), IPAddress(0,0,0,0));
  } else {
    WiFi.config(savedIP(), gatewayIP(), subnetIP(), dnsIP());
  }
}

String formatBSSID(const uint8_t* bssid);

String wifiStatusName(wl_status_t status) {
  switch (status) {
    case WL_IDLE_STATUS: return "IDLE";
    case WL_NO_SSID_AVAIL: return "NO_SSID";
    case WL_SCAN_COMPLETED: return "SCAN_COMPLETED";
    case WL_CONNECTED: return "CONNECTED";
    case WL_CONNECT_FAILED: return "CONNECT_FAILED";
    case WL_CONNECTION_LOST: return "CONNECTION_LOST";
    case WL_WRONG_PASSWORD: return "WRONG_PASSWORD";
    case WL_DISCONNECTED: return "DISCONNECTED";
    default: return String((int)status);
  }
}

void installWiFiDiagnostics() {
  wifiDisconnectedHandler = WiFi.onStationModeDisconnected(
    [](const WiFiEventStationModeDisconnected& event) {
      Serial.println("[WIFI] EVENT deconnexion STA : SSID=" + event.ssid +
                     " / BSSID=" + formatBSSID(event.bssid) +
                     " / reason=" + String(event.reason));
    }
  );
}

void setDefaults() {
  memset(&config, 0, sizeof(config));
  config.magic = CONFIG_MAGIC;

  snprintf(config.name, sizeof(config.name), "TALLY-%02d", DEFAULT_TALLY_NUMBER);
  strlcpy(config.ssid, DEFAULT_WIFI_SSID, sizeof(config.ssid));
  strlcpy(config.wifiPassword, DEFAULT_WIFI_PASSWORD, sizeof(config.wifiPassword));
  strlcpy(config.adminToken, DEFAULT_ADMIN_TOKEN, sizeof(config.adminToken));

  config.dhcp = true;

  config.ip[0] = 192; config.ip[1] = 168; config.ip[2] = 1;
  config.ip[3] = 80 + constrain(DEFAULT_TALLY_NUMBER, 1, 8);

  config.gateway[0] = 192; config.gateway[1] = 168; config.gateway[2] = 1; config.gateway[3] = 1;
  config.subnet[0] = 255; config.subnet[1] = 255; config.subnet[2] = 255; config.subnet[3] = 0;
  config.dns[0] = 192; config.dns[1] = 168; config.dns[2] = 1; config.dns[3] = 1;

  config.tricaster[0] = 192; config.tricaster[1] = 168;
  config.tricaster[2] = 1; config.tricaster[3] = 50;

  config.camera = constrain(DEFAULT_TALLY_NUMBER, 1, 8);

  config.pgmR = 255; config.pgmG = 0; config.pgmB = 0;
  config.prevR = 0; config.prevG = 255; config.prevB = 0;
  config.brightness = 100;
}

void saveConfig() {
  EEPROM.put(0, config);
  EEPROM.commit();
}

void migrateLegacyConfig(const LegacyConfigV3& legacy) {
  setDefaults();

  strlcpy(config.name, legacy.name, sizeof(config.name));
  memcpy(config.ip, legacy.ip, sizeof(config.ip));
  memcpy(config.tricaster, legacy.tricaster, sizeof(config.tricaster));

  config.camera = legacy.camera;
  config.pgmR = legacy.pgmR; config.pgmG = legacy.pgmG; config.pgmB = legacy.pgmB;
  config.prevR = legacy.prevR; config.prevG = legacy.prevG; config.prevB = legacy.prevB;
  config.brightness = legacy.brightness;

  config.magic = CONFIG_MAGIC;
  saveConfig();

  Serial.println("[CONFIG] Ancienne configuration migree vers V4");
}

void loadConfig() {
  EEPROM.begin(1024);

  uint32_t storedMagic = 0;
  EEPROM.get(0, storedMagic);

  if (storedMagic == CONFIG_MAGIC) {
    EEPROM.get(0, config);
  } else if (storedMagic == LEGACY_CONFIG_MAGIC) {
    LegacyConfigV3 legacy;
    EEPROM.get(0, legacy);
    migrateLegacyConfig(legacy);
  } else {
    setDefaults();
    saveConfig();
  }

  config.name[sizeof(config.name) - 1] = '\0';
  config.ssid[sizeof(config.ssid) - 1] = '\0';
  config.wifiPassword[sizeof(config.wifiPassword) - 1] = '\0';
  config.adminToken[sizeof(config.adminToken) - 1] = '\0';
}

void setRGBPWM(int r, int g, int b) {
  float factor = constrain(config.brightness, 1, 100) / 100.0;
  int rr = map((int)(constrain(r, 0, 255) * factor), 0, 255, 0, 1023);
  int gg = map((int)(constrain(g, 0, 255) * factor), 0, 255, 0, 1023);
  int bb = map((int)(constrain(b, 0, 255) * factor), 0, 255, 0, 1023);
  analogWrite(PIN_RED, 1023 - rr);
  analogWrite(PIN_GREEN, 1023 - gg);
  analogWrite(PIN_BLUE, 1023 - bb);
}

void ledsOff() { setRGBPWM(0, 0, 0); }

void fadeRGB(int r1, int g1, int b1, int r2, int g2, int b2, int durationMs) {
  const int steps = 30;
  for (int i = 0; i <= steps; i++) {
    float t = (float)i / steps;
    setRGBPWM(r1 + (r2-r1)*t, g1 + (g2-g1)*t, b1 + (b2-b1)*t);
    delay(durationMs / steps);
    yield();
  }
}

void startupAnimation() {
  fadeRGB(0,0,0, 255,0,0, 150);
  fadeRGB(255,0,0, 255,255,0, 150);
  fadeRGB(255,255,0, 0,255,0, 150);
  fadeRGB(0,255,0, 0,255,255, 150);
  fadeRGB(0,255,255, 0,0,255, 150);
  fadeRGB(0,0,255, 255,0,255, 150);
  fadeRGB(255,0,255, 0,0,0, 150);
  for (int i = 0; i < 3; i++) {
    setRGBPWM(255,255,255); delay(55); ledsOff(); delay(55); yield();
  }
}

void applyTallyLED() {
  if (currentState == STATE_PROGRAM) setRGBPWM(config.pgmR, config.pgmG, config.pgmB);
  else if (currentState == STATE_PREVIEW) setRGBPWM(config.prevR, config.prevG, config.prevB);
  else if (currentState == STATE_ERROR) setRGBPWM(255, 160, 0);
  else ledsOff();
}

void updateLED() {
  if (identifyActive) return;

  // Roaming volontaire : totalement invisible pour le cadreur.
  // On conserve strictement le dernier etat tally pendant le scan et la bascule.
  if (roamScanRunning || roamInProgress) {
    applyTallyLED();
    return;
  }

  // Vraie perte Wi-Fi : bleu fixe pendant la recherche du reseau.
  if (wifiRecoveryState == WIFI_SEARCHING) {
    setRGBPWM(0, 0, 255);
    return;
  }

  // SSID retrouve : bleu clignotant pendant la tentative d'association.
  if (wifiRecoveryState == WIFI_CONNECTING) {
    if ((millis() / BLUE_BLINK_INTERVAL) % 2) setRGBPWM(0, 0, 255);
    else ledsOff();
    return;
  }

  // Securite : si le lien tombe sans que la machine d'etat ait encore reagit.
  if (WiFi.status() != WL_CONNECTED) {
    setRGBPWM(0, 0, 255);
    return;
  }

  // Wi-Fi OK : rouge/vert/off selon le TriCaster, jaune si le TriCaster est perdu.
  applyTallyLED();
}

String jsonEscape(const String& value) {
  String out;
  out.reserve(value.length() + 8);
  for (unsigned int i = 0; i < value.length(); i++) {
    char c = value[i];
    if (c == '"' || c == '\\') { out += '\\'; out += c; }
    else if ((uint8_t)c >= 32) out += c;
  }
  return out;
}

String stateName() {
  if (currentState == STATE_PROGRAM) return "program";
  if (currentState == STATE_PREVIEW) return "preview";
  if (currentState == STATE_ERROR) return "error";
  return "off";
}

String statusJSON() {
  String json = "{";
  json += "\"name\":\"" + jsonEscape(String(config.name)) + "\",";
  json += "\"firmware\":\"" + String(FIRMWARE_VERSION) + "\",";
  json += "\"ip\":\"" + WiFi.localIP().toString() + "\",";
  json += "\"static_ip\":\"" + savedIP().toString() + "\",";
  json += "\"dhcp\":" + String(config.dhcp ? "true" : "false") + ",";
  json += "\"gateway\":\"" + WiFi.gatewayIP().toString() + "\",";
  json += "\"subnet\":\"" + WiFi.subnetMask().toString() + "\",";
  json += "\"dns\":\"" + WiFi.dnsIP().toString() + "\",";
  json += "\"ssid\":\"" + jsonEscape(String(config.ssid)) + "\",";
  json += "\"tricaster\":\"" + tricasterIP().toString() + "\",";
  json += "\"camera\":" + String(config.camera) + ",";
  json += "\"state\":\"" + stateName() + "\",";
  json += "\"rssi\":" + String(WiFi.RSSI()) + ",";
  json += "\"bssid\":\"" + WiFi.BSSIDstr() + "\",";
  json += "\"channel\":" + String(WiFi.channel()) + ",";

  String wifiState = "connected";
  if (roamScanRunning || roamInProgress) wifiState = "roaming";
  else if (wifiRecoveryState == WIFI_SEARCHING) wifiState = "searching";
  else if (wifiRecoveryState == WIFI_CONNECTING) wifiState = "connecting";

  json += "\"wifi_state\":\"" + wifiState + "\",";
  json += "\"brightness\":" + String(config.brightness) + ",";
  json += "\"uptime_ms\":" + String(millis()) + ",";
  json += "\"tricaster_latency_ms\":" + String(lastTriCasterLatency) + ",";
  json += "\"last_tally_age_ms\":" + String(millis() - lastGoodTally) + ",";
  json += "\"roam_count\":" + String(roamCount) + ",";
  json += "\"wifi_loss_count\":" + String(wifiLossCount) + ",";
  json += "\"tricaster_loss_count\":" + String(tricasterLossCount) + ",";
  json += "\"last_roam_age_ms\":" + String(lastRoamCompletedAt == 0 ? 0 : millis() - lastRoamCompletedAt) + ",";
  json += "\"pgm\":[" + String(config.pgmR) + "," + String(config.pgmG) + "," + String(config.pgmB) + "],";
  json += "\"preview\":[" + String(config.prevR) + "," + String(config.prevG) + "," + String(config.prevB) + "]";
  json += "}";
  return json;
}

bool parseIPv4(const String& text, IPAddress& result) {
  int values[4] = {0,0,0,0};
  int part = 0;
  String token;
  for (unsigned int i = 0; i <= text.length(); i++) {
    char c = i < text.length() ? text[i] : '.';
    if (c == '.') {
      if (token.length() == 0 || part > 3) return false;
      for (unsigned int j = 0; j < token.length(); j++) if (!isDigit(token[j])) return false;
      values[part++] = token.toInt();
      token = "";
    } else token += c;
  }
  if (part != 4) return false;
  for (int i = 0; i < 4; i++) if (values[i] < 0 || values[i] > 255) return false;
  result = IPAddress(values[0], values[1], values[2], values[3]);
  return true;
}

bool parseTally(const String& data, bool& program, bool& preview) {
  String lower = data;
  lower.toLowerCase();

  String targetDouble = "name=\"input" + String(config.camera) + "\"";
  String targetSingle = "name='input" + String(config.camera) + "'";

  int namePos = lower.indexOf(targetDouble);
  if (namePos < 0) namePos = lower.indexOf(targetSingle);
  if (namePos < 0) return false;

  int tagStart = lower.lastIndexOf('<', namePos);
  int tagEnd = lower.indexOf('>', namePos);

  if (tagStart < 0 || tagEnd < 0 || tagEnd <= tagStart) return false;

  String tag = lower.substring(tagStart, tagEnd + 1);
  if (tag.indexOf("<column") < 0) return false;

  program = tag.indexOf("on_pgm=\"true\"") >= 0 || tag.indexOf("on_pgm='true'") >= 0;
  preview = tag.indexOf("on_prev=\"true\"") >= 0 || tag.indexOf("on_prev='true'") >= 0;

  return true;
}

bool readTriCaster() {
  if (WiFi.status() != WL_CONNECTED) return false;

  WiFiClient client;
  HTTPClient http;
  String url = "http://" + tricasterIP().toString() + "/v1/dictionary?key=tally";
  http.setTimeout(1000);

  if (!http.begin(client, url)) return false;

  unsigned long requestStart = millis();
  int response = http.GET();
  lastTriCasterLatency = millis() - requestStart;

  if (response != HTTP_CODE_OK) {
    http.end();
    return false;
  }

  String data = http.getString();
  http.end();

  bool pgm = false;
  bool preview = false;
  if (!parseTally(data, pgm, preview)) return false;

  TallyState newState = STATE_OFF;
  if (pgm) newState = STATE_PROGRAM;
  else if (preview) newState = STATE_PREVIEW;

  if (newState != currentState) {
    currentState = newState;
    Serial.println("[TALLY] CAM " + String(config.camera) + " -> " + stateName());
  } else {
    currentState = newState;
  }

  lastGoodTally = millis();
  updateLED();
  return true;
}

void sendHeartbeat() {
  String payload = statusJSON();
  udp.beginPacket(broadcastIP, 4210);
  udp.print(payload);
  udp.endPacket();
}

void handleStatus() {
  server.send(200, "application/json", statusJSON());
}

bool requireAdmin() {
  if (strlen(config.adminToken) == 0) return true;

  if (!server.authenticate("admin", config.adminToken)) {
    server.requestAuthentication();
    return false;
  }

  return true;
}

String htmlEscape(const String& value) {
  String out;
  out.reserve(value.length() + 16);

  for (unsigned int i = 0; i < value.length(); i++) {
    char ch = value[i];
    if (ch == '&') out += "&amp;";
    else if (ch == '<') out += "&lt;";
    else if (ch == '>') out += "&gt;";
    else if (ch == '"') out += "&quot;";
    else if (ch == '\'') out += "&#39;";
    else out += ch;
  }

  return out;
}
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
void loop() {
  server.handleClient();
  unsigned long now = millis();

  // Identification visuelle prioritaire.
  if (identifyActive) {
    if (now - identifyStart >= IDENTIFY_DURATION) {
      identifyActive = false;
      updateLED();
    } else {
      if ((now / 120) % 2) setRGBPWM(255,255,255);
      else setRGBPWM(255,0,255);
    }
  }

  // =================================================
  // ROAMING VOLONTAIRE
  // =================================================
  // Pendant toute cette phase on conserve le dernier rouge/vert/off/jaune.
  // Aucun bleu et aucun faux jaune ne sont montres au cadreur.
  if (roamInProgress) {
    const uint8_t* connectedBssid = WiFi.BSSID();
    bool targetReached = WiFi.status() == WL_CONNECTED &&
                         roamTargetValid &&
                         connectedBssid &&
                         sameBSSID(connectedBssid, roamTargetBssid);

    if (targetReached) {
      roamInProgress = false;
      roamTargetValid = false;
      roamCount++;
      lastRoamCompletedAt = now;
      updateBroadcastIP();
      wifiConnectedAt = now;
      lastGoodTally = now;

      Serial.println("[WIFI] Roaming termine -> " + WiFi.BSSIDstr() +
                     " / canal " + String(WiFi.channel()) +
                     " / RSSI " + String(WiFi.RSSI()) + " dBm");

      // Lecture immediate pour reprendre le vrai etat sans attendre le prochain cycle.
      readTriCaster();
      updateLED();
    } else if (now - lastRoamAt >= ROAM_CONNECT_TIMEOUT) {
      // Le roaming a reellement echoue : seulement maintenant on avertit le cadreur.
      roamInProgress = false;
      roamTargetValid = false;
      Serial.println("[WIFI] Roaming echoue -> passage en recherche Wi-Fi");
      startWiFiRecovery(now); // bleu fixe
    } else {
      updateLED(); // conserve le dernier tally
      delay(2);
      return;
    }
  }

  // =================================================
  // VRAIE PERTE WIFI
  // =================================================
  if (WiFi.status() != WL_CONNECTED) {
    if (wifiRecoveryState == WIFI_NORMAL) {
      startWiFiRecovery(now);
    }

    processRecovery(now);
    delay(2);
    return;
  }

  // Une reconnexion peut devenir WL_CONNECTED avant le prochain passage.
  if (wifiRecoveryState != WIFI_NORMAL) {
    processRecovery(now);

    if (wifiRecoveryState != WIFI_NORMAL) {
      delay(2);
      return;
    }
  }

  // =================================================
  // WIFI OK : ROAMING PREVENTIF
  // =================================================
  handleRoaming(now);

  // Si handleRoaming vient de lancer une bascule, on gele l'affichage tally.
  if (roamInProgress || WiFi.status() != WL_CONNECTED) {
    updateLED();
    delay(2);
    return;
  }

  // =================================================
  // POLLING TRICASTER
  // =================================================
  if (now - lastPoll >= POLL_INTERVAL) {
    lastPoll = now;
    readTriCaster();
  }

  // Pendant un scan de roaming, on ne genere jamais de faux jaune.
  if (!roamScanRunning &&
      millis() - lastGoodTally > TALLY_TIMEOUT &&
      currentState != STATE_ERROR) {
    currentState = STATE_ERROR;
    tricasterLossCount++;
    Serial.println("[TALLY] Wi-Fi OK mais perte des donnees TriCaster -> jaune");
    updateLED();
  }

  // =================================================
  // HEARTBEAT MANAGER
  // =================================================
  if (now - lastHeartbeat >= HEARTBEAT_INTERVAL) {
    lastHeartbeat = now;
    sendHeartbeat();
  }

  delay(2);
}

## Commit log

2026-09-11 Add 3D enclosure download note
2026-09-11 Document enclosure, mounting hardware and power options
2026-09-11 Add 3D enclosure model as encoded asset
2026-09-11 Add printable 3MF enclosure model
    [TALLY_TRICASTER_v6.3mf]
2026-09-11 Remove incomplete 3MF upload
    [TALLY_TRICASTER_v6.3mf]
2026-09-11 Document 3D enclosure hardware
2026-09-18 Add Thingiverse download link for 3D enclosure
2026-09-18 Link 3D enclosure to Thingiverse
2026-09-18 Refine Wi-Fi LED states and make AP roaming invisible
2026-09-18 Fix V4 network defaults and static config
    [TriCaster_Elite2_Tally_ESP8266.ino]
2026-09-18 Add V4.1 production UI, preflight, lock and staged OTA controls
2026-09-18 Implement verified staged OTA and production event monitoring
2026-09-18 Expose current DHCP IP and saved static IP
2026-09-19 Provide ready-to-flash TALLY-04 Arduino sketch V4.1.2
2026-09-19 Fix Wi-Fi diagnostic helper declaration
    [TriCaster_Elite2_Tally_ESP8266.ino]
2026-09-19 Print ESP station MAC for Wi-Fi diagnostics
2026-09-19 Print TALLY-04 station MAC for router diagnostics
2026-09-19 Disable proactive Wi-Fi scans for V4.1.4 stability
    [TriCaster_Elite2_Tally_ESP8266.ino]
